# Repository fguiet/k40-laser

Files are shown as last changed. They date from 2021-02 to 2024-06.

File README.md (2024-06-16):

# K40 Laser

## Foreword

This is all about my K40 Laser improvements ...

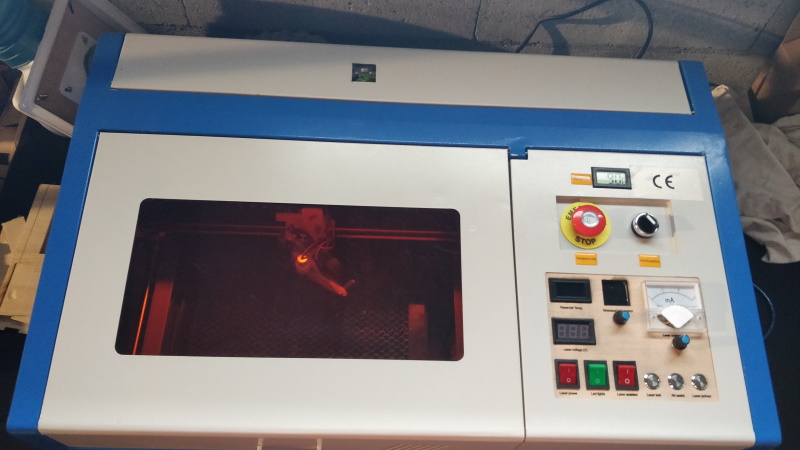
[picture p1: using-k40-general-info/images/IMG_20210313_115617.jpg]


Thanks goes to (Great French resources) :

* Jean-Philippe Civade : <https://www.civade.com>
* Barbatronic : 

Youtube : <https://www.youtube.com/barbatroniclive>

Twitch : <https://www.twitch.tv/barbatroniclive>

Twitter : <https://twitter.com/barbatronic>

## General information / Caution / Rule of thumb / Recommandations

Details avalaible [here](using-k40-general-info/using-k40-laser-cutter.md)

## K40 - Legs/foot improvement

Details avalaible [here](custom-foot/foot-improvements.md)

__Documentation status :__

2021/03/13 : Up to date and finished

## K40 - Custom motorized bed

Details avalaible [here](motorized-bed/motorized-bed-upgrade.md)

__Documentation status :__

2021/03/13 : Add paragraph on how using bed level software with pictures

... WORK IN PROGRESS ... DOCUMENTATION BEING WRITTEN ... WORK IN PROGRESS ... 

TODO : add electronic datasheet

## K40 Upgrade control panel

Details avalaible [here](control-panel/control-panel-upgrade.md)

__Documentation status :__

2021/03/13 : Add photo of my upgraded control panel

... WORK IN PROGRESS ... DOCUMENTATION BEING WRITTEN ... WORK IN PROGRESS ... 

TODO : write all the documentation of the modifications I did + add electronic datasheet

## K40 - Air Assist

Details avalaible [here](air-assist/air-assist.md)

## K40 - Lens & Mirrors alignments and upgrade

TODO

## K40 - Setting proper laser focus

Details avalaible [here](laser-focus/setting-laser-focus.md)

## K40 - Flowmeter holder

Details avalaible [here](flowmeter/flowmeter-upgrade.md)

## Bibliography / References

* [Great French references about K40 Laser Cutter - Github Barbatronic](https://github.com/nadarbreicq/Barbatronic/tree/master/laser%20k40)

Barbatronic's GitHub is full of DIY resources (robotic, PCD, FreeCAD, etc)

* [In French - General information - Blog de Iooner](https://iooner.io/k40-laser/)

* [Amélioration de la K40 - pointeur laser et Air Assist](https://www.youtube.com/watch?v=AwNY7BHcYXY)

* [K40 Tutorials / Ressources](https://k40.se/)

* [In French - Xmas ball](https://www.youtube.com/watch?v=sS2zOudljEQ)

* [In French - Améliorations / Hacking](https://www.civade.com/post/2020/08/23/D%C3%A9coupe-laser-CO2-K40-Am%C3%A9liorations-/-hacking-de-la-machine)

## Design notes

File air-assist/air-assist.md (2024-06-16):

# K40 Air Assist upgrade

A French guy called `Barbatronic` has made a very cool air assist design. Here is a link to the video (in French) where he explained how it did it : <https://www.youtube.com/watch?v=AwNY7BHcYXY>

STL files can be downloaded here : <https://github.com/nadarbreicq/Barbatronic/tree/master/laser%20k40/air%20assist/stl>

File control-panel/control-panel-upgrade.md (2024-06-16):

# K40 - Control panel upgrade

__!!! WORK IN PROGRESS ... DOCUMENTATION BEING WRITTEN ... WORK IN PROGRESS ... !!!__

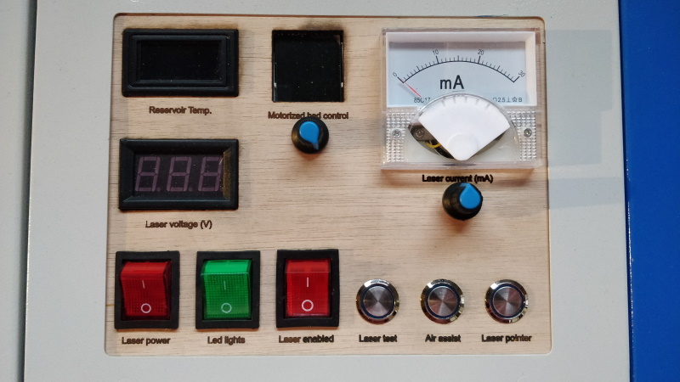
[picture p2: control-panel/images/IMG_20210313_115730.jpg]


Upgrade analog power setting
https://k40.se/k40-laser-upgrades/analog-power-setting/

## Bill of Materials

| Designation | Quantity | Price (euros) |
|:---:|:---:|:---:|
| [Blue Circle + fixed self-locking + China + 9-30V(12V) + 16mm](https://fr.aliexpress.com/item/4001291695467.html?spm=a2g0s.9042311.0.0.1fc66c37ERyqmR) | 2 | 1.69 |
| [Blue Circle + Momentary self-reset + China + 9-30V(12V) + 16mm](https://www.aliexpress.com/item/12-16-19-22mm-Waterproof-Metal-Push-Button-Switch-LED-Light-Momentary-Latching-Car-Engine-Power/4001291695467.html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) | 1 | 1.50 |

TODO : To be continued ...

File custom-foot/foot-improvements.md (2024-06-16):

# K40 Laser - foot improvements

My K40 came with "roller foot /leg" (dunno the exact english translation). What on earth did they install roller foot on that device...in my opinion this is quite useless !

A french guy called `Barbatronic` designed simple cool standstill legs that can be 3D printed.

Here is the STL file link : <https://github.com/nadarbreicq/Barbatronic/tree/master/laser%20k40/pieds%20laser>

Even better he did a very nice video about this improvement (this guy is amazing!) : <https://www.youtube.com/watch?v=EUyNfkmQzwM&feature=youtu.be>

In the beginning, I wanted to design my own legs but eventually I used nice `Barbatronic` design !

Here is the result :

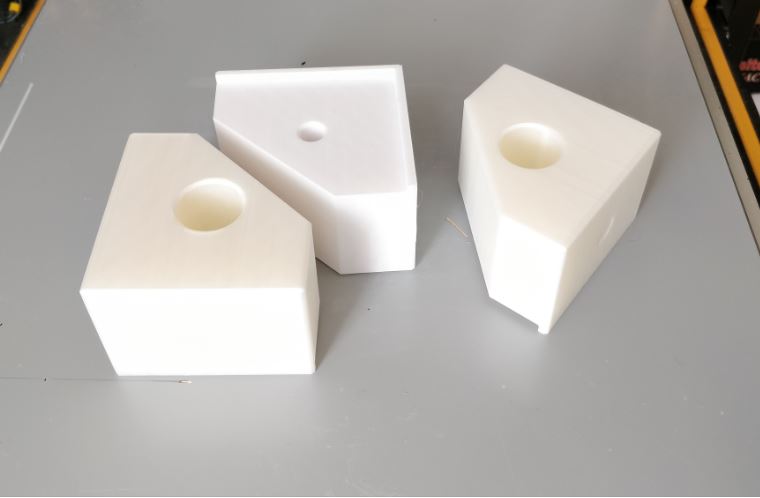
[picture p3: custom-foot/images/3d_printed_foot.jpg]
3D Printed foot


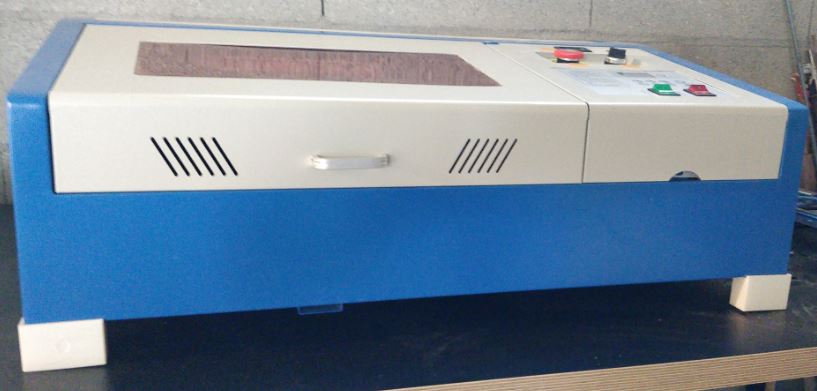
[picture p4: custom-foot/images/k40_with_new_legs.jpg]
3D Printed foot


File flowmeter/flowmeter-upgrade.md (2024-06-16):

# Flowmeter holder

This is a flowmeter holder I realised with FreeCAD 0.20

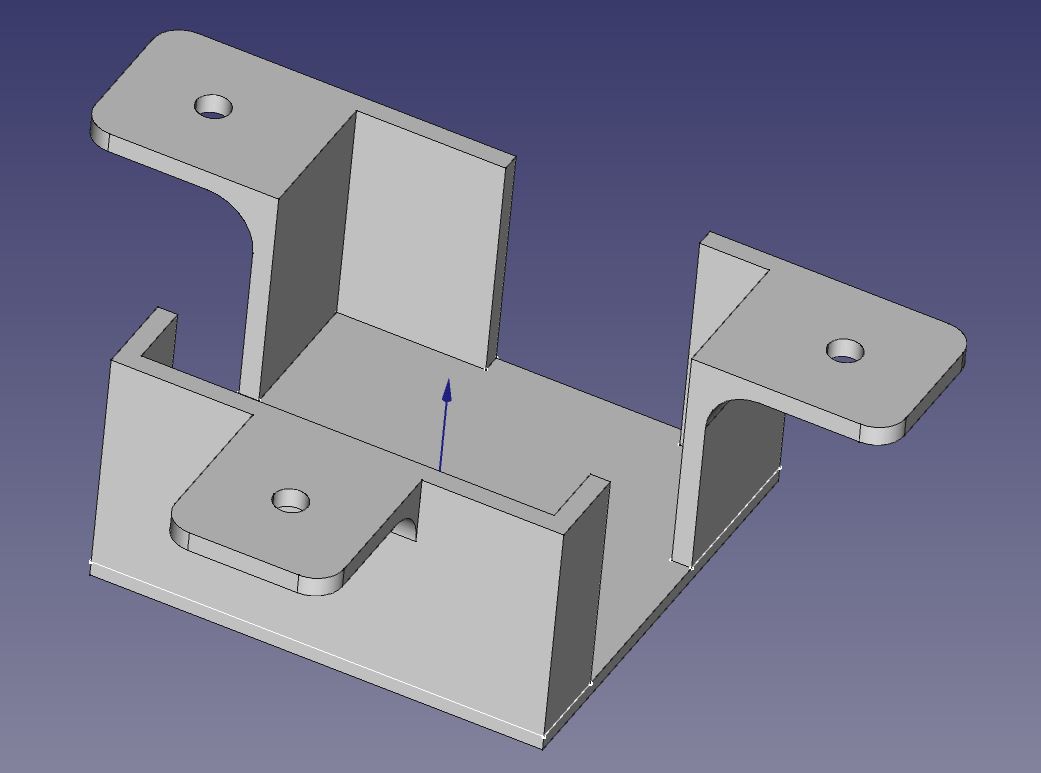
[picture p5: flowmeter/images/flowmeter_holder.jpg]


It may be used to hold this kind of flowmeter, one can found on [Aliexpress](https://fr.aliexpress.com/item/32822267913.html?spm=a2g0o.9042311.0.0.1ec66c37fij9EE).

Dimension 40x40x25 mm

But mine is 40,4mm x 40,4mm x 21,6 mm

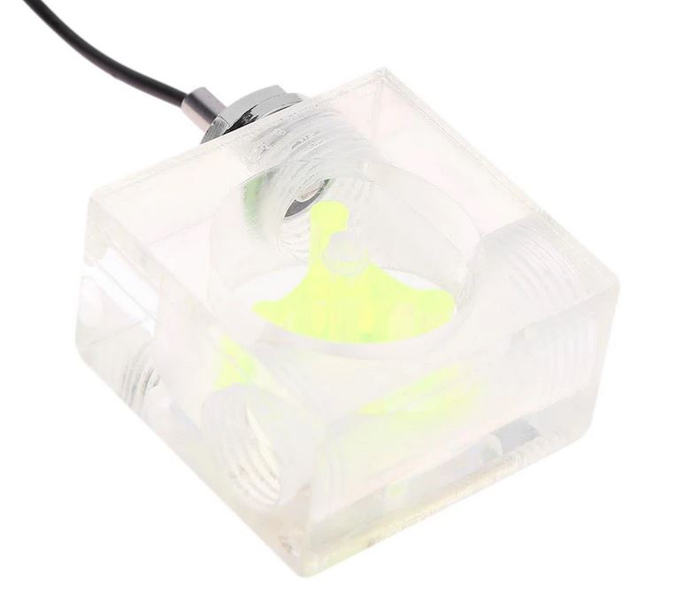
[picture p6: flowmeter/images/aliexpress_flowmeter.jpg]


Feel free to download the

* [STL File](stl/flowmeter_holder.stl)
* [FreeCAD File](FreeCAD/flowmeter_holder.FCStd)

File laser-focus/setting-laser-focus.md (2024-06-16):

# Setting laser focus

K40 laser cutter comes with a focal length of 50.8 mm. So in theory, your bed level should be good if your bed is 50.8 mm away from the laser lens.

There is a good video you can watch here : <https://www.youtube.com/watch?v=u4YHbDBBofg&t=301s>

* Make your bed level. To do that mesure the distance from the nut to top part of the bolt.
The distance must be the same on the four bed corners.

* Select "Move to bed origin" on the control panel menu. Your bed will go down to the origin.

* Use a piece of plywood and a block in order to make a ramp.

* Use `Inkscape` to draw a 20 cm line. Set the outline in blue (Recognized as Laser engrave in `Whisperer`)

* Use `Whisperer` to laser engrave the plywood (20 mm/s at 5mA, those settings can be ajusted)

* Find the spot where the line is the narrowest

* Use a rule to measure the distance between where the line is the narrowest and the laser head

* On the control panel menu, select `Move from origin to bed focal` and use `Bed offset from origin to focal` to adjust the distance from the bed to the laser head with the distance measured just before

* Save your settings : from main menu `Settings`, and `Save settings`

* You're done !

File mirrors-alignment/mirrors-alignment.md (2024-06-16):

# K40 - Lens & Mirrors alignments and upgrade

TODO

https://www.youtube.com/watch?v=e1c3keOKL6Y

## Bill of Materials

| Name | Price  |
|:---:|:---:|
| [SI 20x3mm 3Pcs + 50.8mm + Focus Lens 12mm 1Pcs](https://fr.aliexpress.com/item/32989511290.html?spm=a2g0s.9042311.0.0.1fc66c37ERyqmR) | 20.19 Euros |

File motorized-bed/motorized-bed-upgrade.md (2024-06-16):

# K40 - Motorized bed upgrade

__!!! WORK IN PROGRESS ... DOCUMENTATION BEING WRITTEN ... WORK IN PROGRESS ... !!!__

Quick and dirty videos, I have made : 

* <https://youtu.be/IQfGlTcqH2U>

* <https://youtu.be/5MnR36rrxaM>

## Foreword

K40 Laser cutter comes with an awful useless bed so I decided to make my own motorized bed.

There are some resources on the Internet about how to realize a motorized bed for your K40 Laser cutter.

In particular, I was inspired by:

__mumpitz_82__ Youtube video : <https://www.youtube.com/watch?v=evmyce_BSfk>

__Tako Schotanus__ Youtube video : <https://www.youtube.com/watch?v=CWHxK8Uck-s>

But the best resources is from Jean-Philippe Civade : <https://www.civade.com> (it's in French though) :

<https://www.civade.com/post/2020/08/23/D%C3%A9coupe-laser-CO2-K40-:-R%C3%A9alisation-d-un-lit-motoris%C3%A9>

Everything is explained in details. Thanks for sharing !

## Making the motorized bed frame

Top view

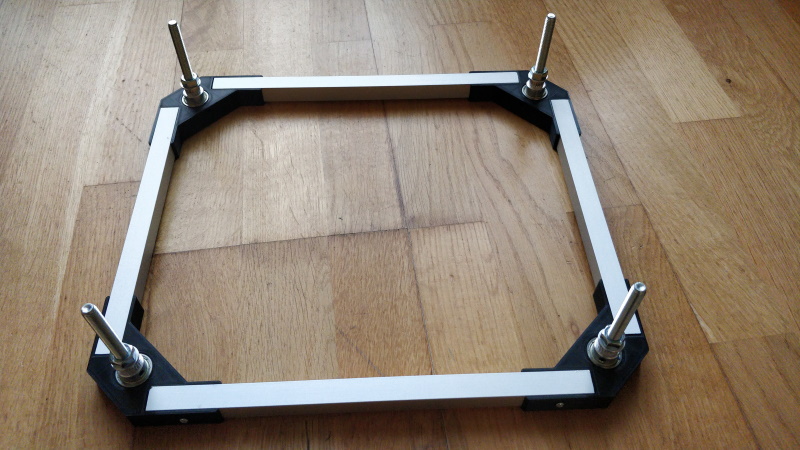
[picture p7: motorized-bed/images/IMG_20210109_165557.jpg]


Bottom view

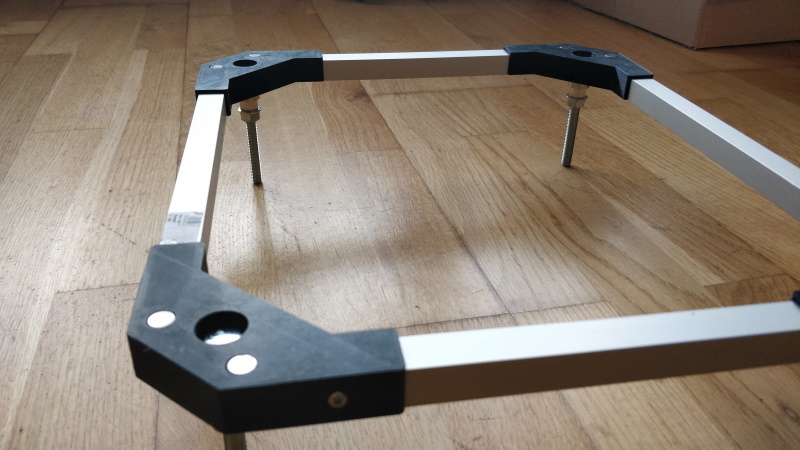
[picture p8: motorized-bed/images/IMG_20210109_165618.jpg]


With belt (final version does not have the belt tensioner. I am using 1250 mm that fits my design now)

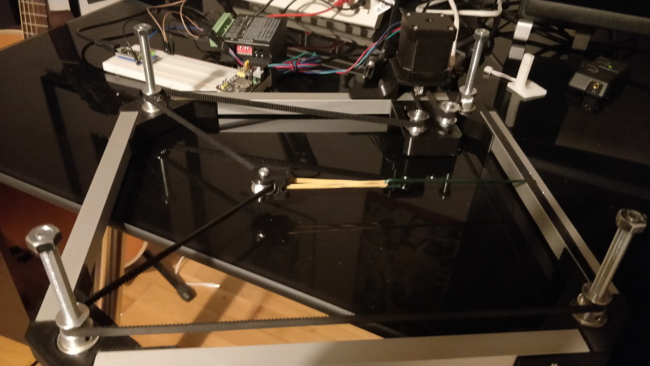
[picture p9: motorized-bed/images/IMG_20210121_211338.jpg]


With belt and bed (final version does not have the belt tensioner. I am using 1250 mm that fits my design now)

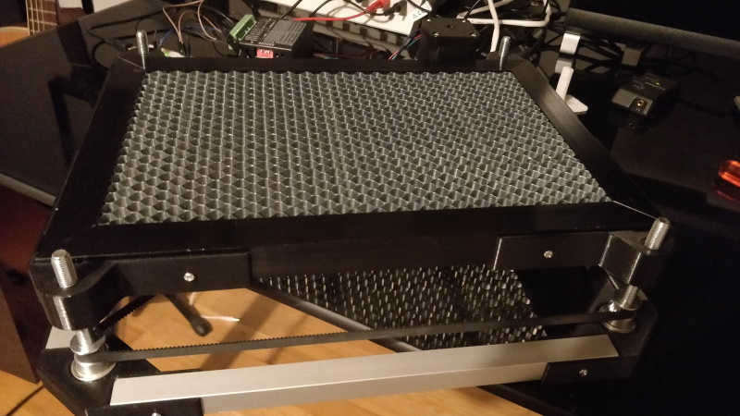
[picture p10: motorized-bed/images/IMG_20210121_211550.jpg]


All 3D print parts needed are available here : <https://www.thingiverse.com/thing:4778552>

* 3D Print 4 corners : STL file `motorized-bed-base-corner-frame.stl`
* Cut 4 pieces of 15 x 15 mm aluminium tube (2 pieces of 26.1 cm lenght and 2 pieces of 22.2 cm lenght)
* Assemble the 3D print parts and the aluminium tubes
* Use a 2.5 mm drill bit to drill hole in the aluminium part
* Use a tap and die (Tarauds in French) M3 x 0.5mm 
* Use 8 x M3 bolt to tight the 3D Print part with the alumnium part
* Add the four 608ZZ bearings on the 3D Print parts
* Add the four M8 x 8mm bolts and nuts
* Add the four GT2 8mm (diameter) x 6 mm height pulleys 
* You're done !
* BONUS : Add 8 neodymes magnet (8mm x 1mm) of the bottom corner

## Bed level software

Software used to develop : Visual Studio Code + PlatformIO plugin.

Self-explanatory open source code, see folder : `sketches\k40-motorized-bed` on this GitHub.

* Using the bed level software

__Powering the K40 laser ON__

1. make the splash screen quickly appear
2. bed will retrieve its origin
3. bed will move up to the material focal point (engrave) level, that is to say : 

bed level to best laser focal length lens (should be around 50.8 mm) minus material thickness

Example in my case:

14 mm - 5 mm = 9 mm 

14 mm : distance of the bed from the bed origin so the laser focal distance from the bed is around 50.8 mm (default K40 focal length lens). See [Settings laser focus](../laser-focus/setting-laser-focus.md), to understand how I find my setting of 14 mm

5 mm : current material thickness (can be changed)

Splash screen

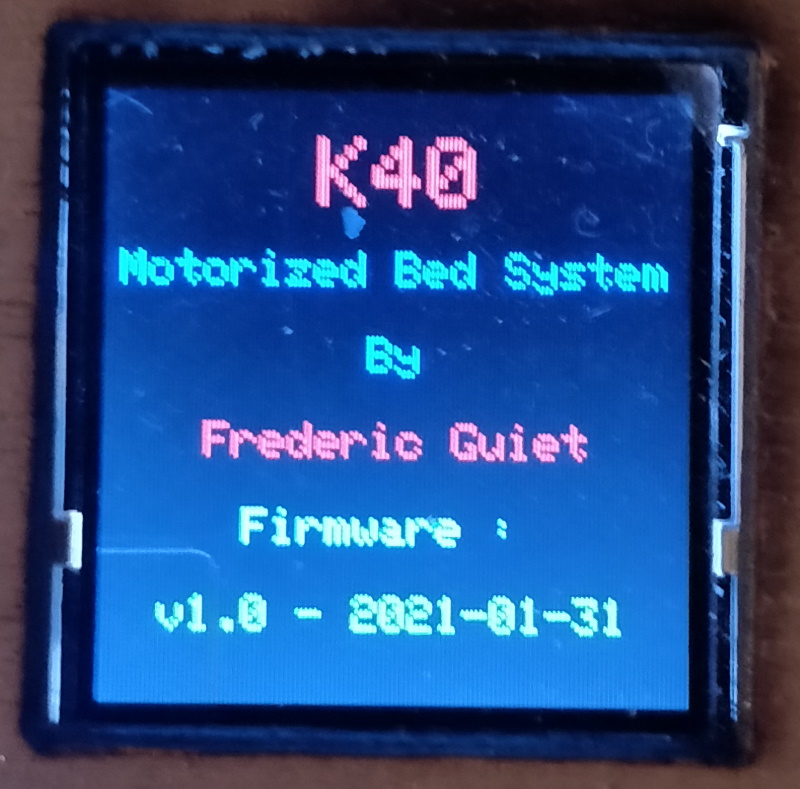
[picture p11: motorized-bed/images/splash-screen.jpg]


Bed retrieving its origin

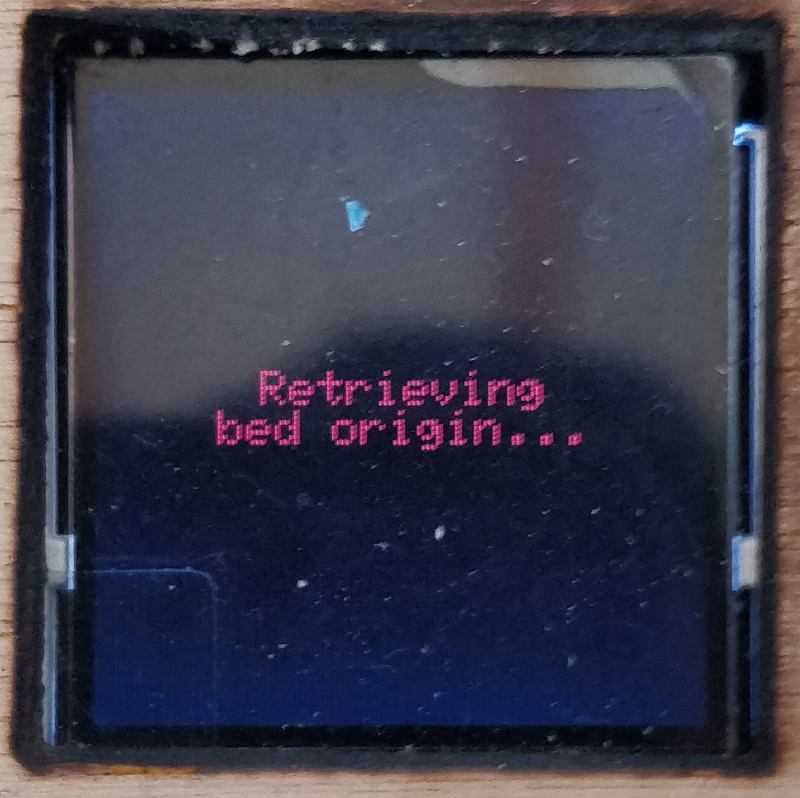
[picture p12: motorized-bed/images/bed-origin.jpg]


__Main menu__

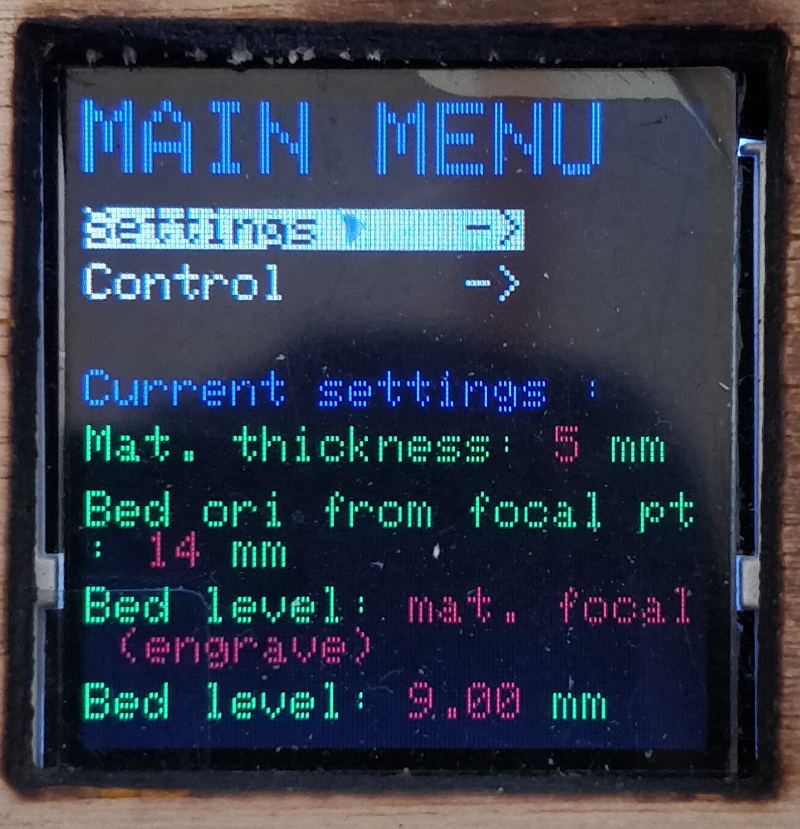
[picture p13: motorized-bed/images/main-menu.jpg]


Main menu is made up of (to enter any menu, just hold the button for about half a second) :

1. Settings menu

When entering this menu, you will be able to set/change default material thickness, bed offset from origin to best focal lenght lens (See [Settings laser focus](../laser-focus/setting-laser-focus.md))

2. Control menu 

When entering this menu, you will be able to move the bed to different level (origin, engrave, cut)

3. Current settings values

This is a sum up of the current settings. 

Current material thickness

Current bed origin to best focal point distance. See [Settings laser focus](../laser-focus/setting-laser-focus.md)

Bed level status : engrave (= laser focal point minus material thickness), cut (= laser focal point minus material thickness / 2), origin, laser focal point (distance between bed and laser lenght should be around 50.8 mm)

Current bed level from origin (depends on bed status)

__Settings menu__

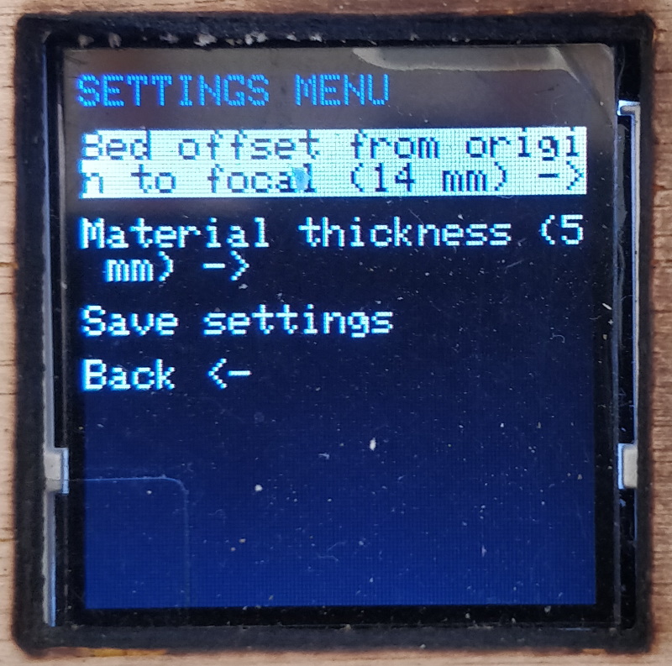
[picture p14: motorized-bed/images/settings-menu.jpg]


Here you can change defaults parameters and save them.

You can change :

The default distance between bed origin and the bed so the bed distance between bed and best focal length lens is around 50.8 mm (again see [Settings laser focus](../laser-focus/setting-laser-focus.md)). Use the menu `Bed offset from origin to focal (xx mm) ->`

The default material thickness. This setting is used to compute automatically the bed level used for engraving or for cutting. Use the menu `Material thickness (x mm) ->`

The following formulas are applied :

Bed level (cut) = bed level offset from origin to best focal point minus material thickness divided by 2
Bed level (engrave) = bed level offset from origin to best focal point minus material thickness

To change the value : hold the button for half a second then you will be able to change the value by turning the button clockwise or anti-clockwise

You can persist your settings by entering the `Save settings` menu

__Control menu__

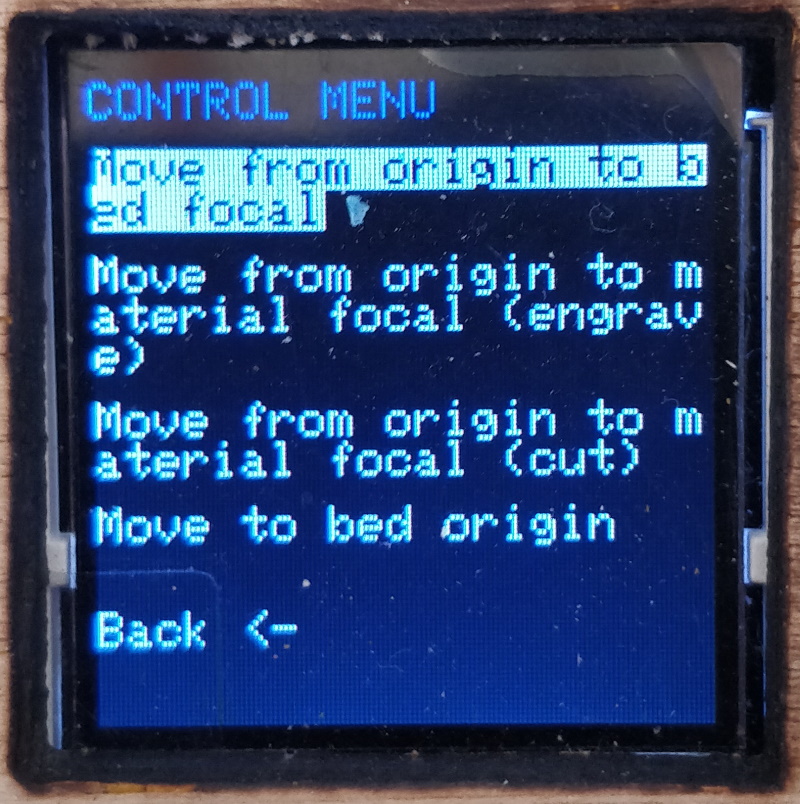
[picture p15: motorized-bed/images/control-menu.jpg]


With the control menu, you will be able freely change your bed level.

`Move from origin to focal (xx mm)` : make your bed go from bed origin to focal point ... quite obvious...the distance can be set using `Settings menu`

`Move from origin to material focal (engrave)` : make your bed go from bed origin to focal point minus material thickness

`Move from origin to material focal (cut)` : make your bed go from bed origin to focal point minus material thickness divided by 2

`Move to bed origin` : make your bed go to the bed origin (lowest point the bed can go). Maybe useful if you want to pull your bed out of your K40.

## Electronic datasheet

TODO : __!!! WORK IN PROGRESS ... DOCUMENTATION BEING WRITTEN ... WORK IN PROGRESS ... !!!__

## BOM (Bill of materials)

| Designation | Quantity | Price (euros) |
|---|---|---|
| [Neodyme magnet 8mm x 1mm](https://fr.aliexpress.com/item/1005001485065704.html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,searchweb201602_,searchweb201603_) | 10 | 1.6 |
| [Roulement 608ZZ](https://www.amazon.fr/gp/product/B07RZ651J7/ref=ppx_yo_dt_b_search_asin_title?ie=UTF8&psc=1) | 1 | 10 |
| [Module LCD TFT couleur SPI 1.44 pouces série 128x128](https://fr.aliexpress.com/item/32805710090.html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,searchweb201602_,searchweb201603_) | 1 | 2.36 |
| [Power supply : 12v, 3A](https://fr.aliexpress.com/item/32983648084.html?spm=a2g0s.9042311.0.0.27426c379UWNDo) | 1 | 5.47 |
| [Module d'encodeur rotatif 360 degrés](https://fr.aliexpress.com/item/32648520888.html?spm=a2g0s.9042311.0.0.1ec66c37pUfP6L) | 1 | 0.67 |
| [Arduino Uno](https://fr.aliexpress.com/item/32272099710.html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,searchweb201602_,searchweb201603_) | 1 | 2.86 |
| M3 Bolt | 8 | ? |
| Bolt M8 x 80mm | 4 | ? |
| Nut M8 | 4 | ? |
| [End stop switch](https://fr.aliexpress.com/item/32824972155.html?spm=a2g0s.9042311.0.0.27426c37mAJldV) | 1 | 0.59 |
| [GT2 Belt 1250 mm](https://fr.aliexpress.com/item/4000307078477.html?spm=a2g0s.9042311.0.0.70226c377k5Fyv) | 1 | 1.76 |
| [Entretoise](https://www.amazon.fr/gp/product/B07RP6CRD5/ref=ppx_yo_dt_b_asin_title_o01_s00?ie=UTF8&psc=1) | 1 | 15 |
| [Stepper Driver Motor TB6600](https://www.amazon.fr/gp/product/B0811GSPJK/ref=ppx_yo_dt_b_asin_title_o04_s00?ie=UTF8&psc=1) | 1 | 13.49 |
| [Tube carré - aluminium, couleur argent, anodisée, 1000 x 15 x 15 mm](https://www.amazon.fr/gp/product/B0029ZTDKM/ref=ppx_od_dt_b_asin_title_s00?ie=UTF8&psc=1) | 3 | 8.36 |
| [DollaTek 5PCS Aluminium GT2 Courroie De Distribution Poulie 20 Dents Alésage 8mm Largeur 6mm et Clé pour RepRap 3D Imprimante Prusa i3](https://www.amazon.fr/gp/product/B07DK1J8ZD/ref=ppx_yo_dt_b_asin_title_o09_s01?ie=UTF8&psc=1) | 1 | 8 |
| [Quimat 3x Nema 17 Stepper Moteur,Moteurs pour Imprimante 3D 1.7A 0.59Nm](https://www.amazon.fr/gp/product/B06XQWMDWT/ref=ppx_yo_dt_b_asin_title_o09_s02?ie=UTF8&psc=1) | 1 | 40 |
| [Table de travail en nid d'abeille pour graveur Laser CO2, pièces pour Machine de découpe Shenhui SH K40 graveur de timbres 320x220mm](https://fr.aliexpress.com/item/32603523206.html?spm=a2g0s.9042311.0.0.27426c37F8tu4Z) | 1 | 13.96 |

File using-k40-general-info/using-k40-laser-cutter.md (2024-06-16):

# Using K40 Laser Cutter – The rules of thumb

## Default Settings

* Laser cut area (my upgraded version) : 280mm x 180 mm

* Laser tube power : 40 W

* Lens diameter : 12 mm

* Focal lenght : 50.8 mm

* 3 Mirrors : 20 mm

I bought mine on AliExpress : <https://fr.aliexpress.com/item/1005001374933857.html?spm=a2g0s.9042311.0.0.27426c37F8tu4Z>

I have choosen a warehouse located in Czech Republic and I have paid : __349 euros (with DHL shipping included)__

## Powering the CO2 Tube

* [Do not overpower the CO2 Tube](https://k40.se/k40-laser-troubleshooting/dead-lasertube/). Keep the ammeter below 18mA (which is around 2.5v on the voltmeter of my K40).

Below the value in mA I get when I set some value on the voltmeter (Caution, this is my settings, it may differ on yours) 

| Value set on the Voltmeter (in V) | Match value on the ammeter (in mA) |
|---|---|
| 0.5 | 3 |
| 1 | 7 |
| 1.25 | 9 |
| 1.4 | 10 |
| 1.5 | 10-11 |
| 1.6 | 11 |
| 1.8 | 12 |
| 2 | 13 |
| 2.1 | 14 |
| 2.3 | 15 |
| 2.5 | 16 |
| 2.7 | 17 |
| 2.9 | 18 |

## Cooling water

* Only use pure distilled water, never add watercooling stuff

## Before turning the machine ON

* __Put your CO2 Laser proof google on__
* Check all buttons are in OFF position
* Check that your potentiometer is set to the minimum (ie you should not be able to turn it anticlockwise)
* [Check CO2 Laser tube water temperature](https://k40.se/k40-laser-troubleshooting/dead-lasertube/), it should be between 15-20 °C. It can run if temperature is between 21-23°C but it reduces the CO2 tube life time.
* From time to time, check bed leveling

## Turning the machine ON

1.	Turn the water pump ON and eliminate all the bubbles in the CO2 Laser tube (on my laser I need to raise it towards me to get rid of bubbles on the left side of the laser tube)
2. 

TODO : Finish this part

## What can be cut ?

French ressource : <https://iooner.io/decoupe-laser-les-materiaux/>

Some working parameters I have tested:

* Plywood (don't think it is made of poplar...)

Cut : 5 mm/s, 16 mA (2.5v)...but there are places not cut very well...dunno why (laser alignment? bed leveling?)

## BOM (Bill Of Materials)

| Name | Price  |
|:---:|:---:|
| [CO2 Laser protection google  9000-11000 nm](https://www.amazon.fr/gp/product/B07JCSH4HC/ref=ppx_yo_dt_b_asin_title_o02_s00?ie=UTF8&psc=1) | 40 Euros |

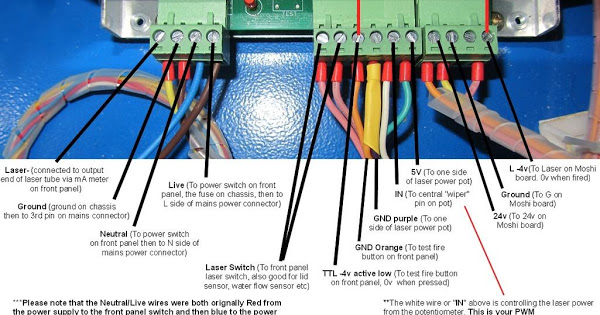
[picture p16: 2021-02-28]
control-panel/images/power_pinout.jpg

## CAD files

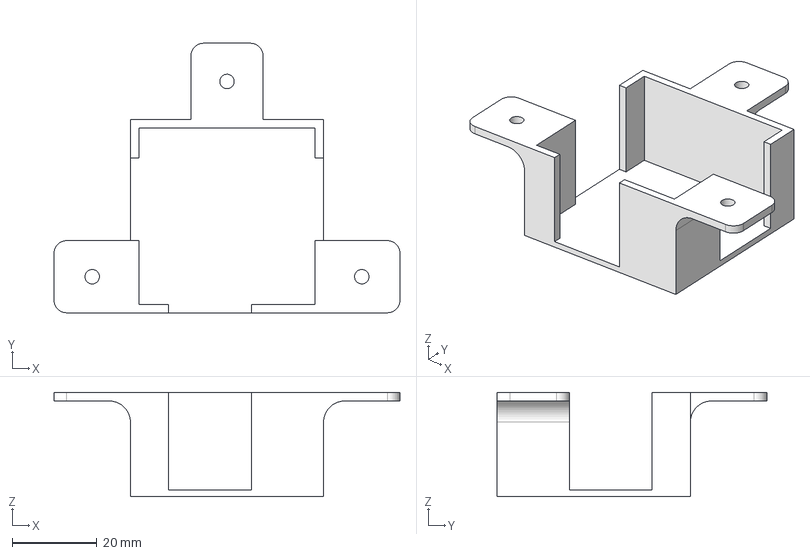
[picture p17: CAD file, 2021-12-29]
flowmeter/FreeCAD/flowmeter_holder.FCStd
81.5 x 63.5 x 24.5 mm

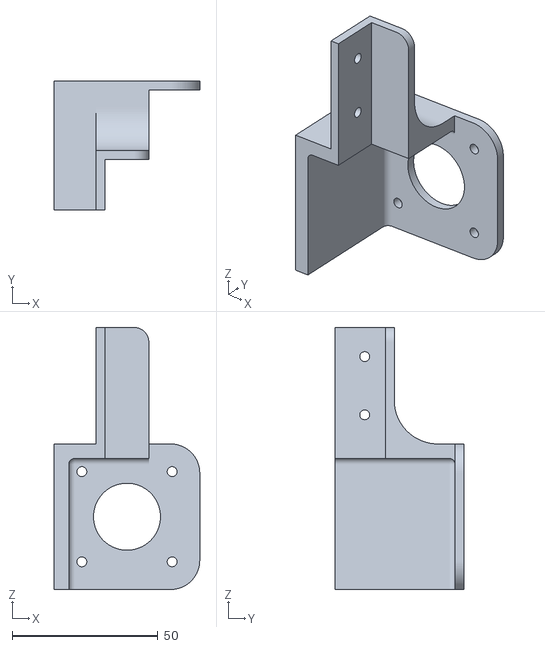
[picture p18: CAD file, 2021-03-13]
motorized-bed/stl/motorized-bed-nema17-holder.stl
50.0 x 44.2 x 90.0

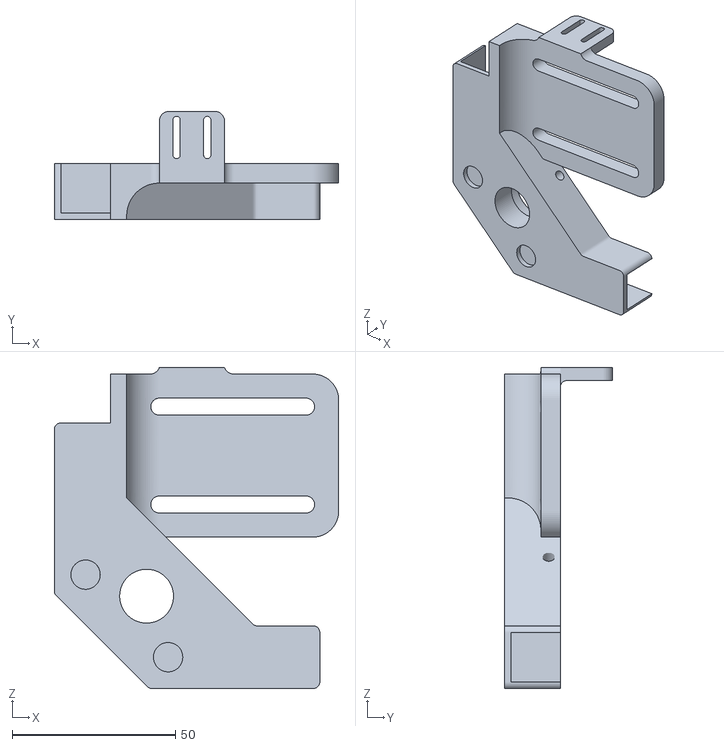
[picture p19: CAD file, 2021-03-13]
motorized-bed/stl/motorized-bed-base-upper-right-corner.stl
87.2 x 33.2 x 98.4

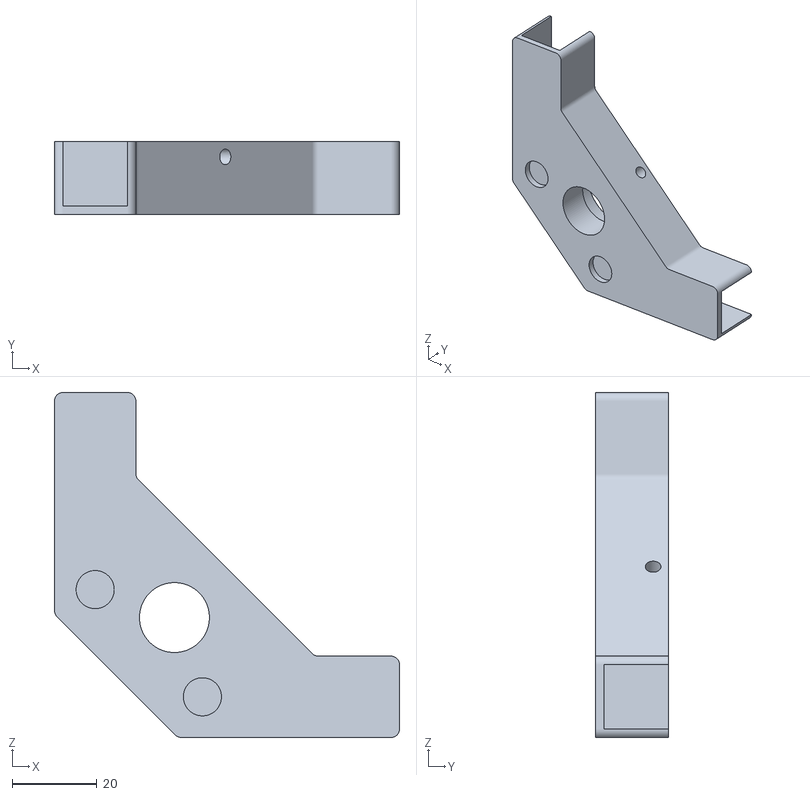
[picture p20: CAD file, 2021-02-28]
motorized-bed/stl/motorized-bed-base-corner-frame.stl
81.4 x 17.2 x 81.4

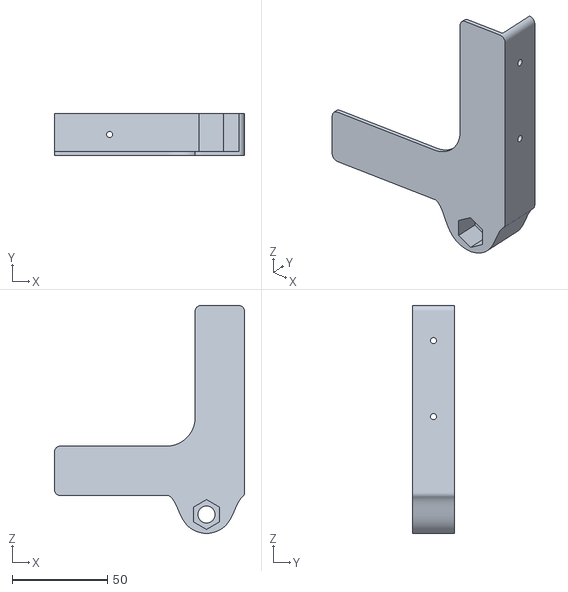
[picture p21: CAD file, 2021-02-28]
motorized-bed/stl/motorized-bed-upper-right-corner.stl
100.0 x 22.0 x 120.0

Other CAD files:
motorized-bed/stl/motorized-bed-bottom-left-corner.stl
motorized-bed/stl/motorized-bed-upper-left-corner.stl
motorized-bed/stl/motorized-bed-bottom-right-corner.stl
flowmeter/stl/flowmeter_holder.stl

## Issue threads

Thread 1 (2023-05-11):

k40-motorized-bed

interceptor70, 2023-05-11:
Hi from Germany

s the project still active?

how can i adjust two lenses i need one 50 and one 90 mm
can this be expanded?

LG Interceptor

interceptor70, 2023-06-03:
need 0.1 mm thigness auch

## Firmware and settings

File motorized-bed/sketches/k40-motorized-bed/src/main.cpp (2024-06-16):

/*
* K40 laser cutter - Motorized bed
* Frédéric Guiet - 01/2021
* 
* I wrote this piece of software but it is inspired from the one wrote by Jean-Philippe Civade : https://www.civade.com/post/2020/08/23/D%C3%A9coupe-laser-CO2-K40-%3A-R%C3%A9alisation-d-un-lit-motoris%C3%A9
*
*/

// ****** External librairies used ******

#include <SPI.h>            // needed by TFT_ILI9163C
#include <Adafruit_GFX.h>   // Adafruit graphic library needed by TFT_ILI9163C
#include <Wire.h>           // needed by TFT_ILI9163C
#include <ezButton.h>       // Button management
#include <Encoder.h>        // Panel encoder management from Paul Stoffregen
#include <AccelStepper.h>   // To manager stepper with acceleration
#include <TFT_ILI9163C.h>   //TFT ILI9163C 128x128 Screen management

// ****** DEBUG *************************

#define DEBUG 1

// ***** FIRMWARE ***********************

#define FIRMWARE "v1.0 - 2021-01-31"

// **************************************

// ****** NEMA17 MOTOR SETTINGS *********

//* Motor NEMA 17 (https://www.amazon.fr/gp/product/B06XQWMDWT/ref=ppx_yo_dt_b_asin_title_o06_s01?ie=UTF8&psc=1)
//*
//* NEMA 17, Peak current 1.7A, 200 steps per revolution, 1.8° per step
//*
//* Driver TB6600 (https://www.amazon.fr/gp/product/B0811GSPJK/ref=ppx_yo_dt_b_asin_title_o01_s00?ie=UTF8&psc=1)
//*
//* Microstep settings
//* Stepper motors typically have a step size of 1.8° or 200 steps per revolution, this refers to full steps. A microstepping driver such as the TB6600 allows higher resolutions by allowing intermediate step locations. This is achieved by energizing the coils with intermediate current levels.
//* For instance, driving a motor in 1/2 step mode will give the 200-steps-per-revolution motor 400 microsteps per revolution.
//* You can change the TB6600 microstep settings by switching the dip switches on the driver on or off. See the table below for details. Make sure that the driver is not connected to power when you adjust the dip switches!
//*
//* Steps (1,2,3) = 0ff, On, Off = 1/8 step
//* Power (4,5,6) = On,On, Off) = 1.5A nominal / 1.7 Peak
//*
//* Wire Blue = B+
//* Wire Red  = B-
//* Wire Green = A+
//* Wire Black = A-
//
// So...
//
// See : https://fr.wikipedia.org/wiki/Filetage_m%C3%A9trique
//
// * 200 * 8 = 1600 micro-step / turn.
// * Screw M8 x 1.25 (1.25 mm per thread)
// * 1 turn = 1.25 mm = 1600 steps
// * 1mm = (1600/1.25)*1 = 1280 steps
// * 0.1mm = 128 steps

// Pin configuration Arduino to TP6600 Driver
// Arduino Digital pin 4 to PUL-(PUL)
// Arduino Digital pin 5 to DIR-(DIR)
// Arduino Digital pin 6 to ENA-(ENA)

// Stepper connections
#define  STEP_PIN 4             // Step/Pulse interface ()
#define  DIRECTION_PIN 5        // Dir interface (Nema 17 Direction)
#define  ENABLE_PIN 6           // Enable stepper motor (Enable / disable current on Nema 17)

// Stepper constants
#define STEPS_PER_MM 1280.0      // Number of step needed for 1 mm

// Library objects instantiation
AccelStepper bed(AccelStepper::DRIVER, STEP_PIN, DIRECTION_PIN);

#define MAX_BED_OFFSET_FROM_ORIGIN 18 //max offset from switch to bed focal zero (mm)
#define MAX_MATERIAL_THICKNESS 50  //max material thickness (mm)

#define DEFAULT_BED_OFFSET_FROM_ORIGIN 18 //Default offset from switch to bed focal zero (mm)
#define DEFAULT_MATERIAL_THICKNESS 5  //Default material thickness (mm)

#define RESET_FLASH_MEMORY_PIN 8

// ********** BED STATUS ************

enum bedStatus { FROM_ORIGIN_TO_BED_FOCAL_POINT_LEVEL, FROM_ORIGIN_TO_MATERIAL_ENGRAVE_FOCAL_POINT_LEVEL, FROM_ORIGIN_TO_MATERIAL_CUT_FOCAL_POINT_LEVEL, FROM_ORIGIN_LEVEL };

// bed settings vars
typedef struct {    
    int bedOffsetFromOriginToFocalPoint_mm = DEFAULT_BED_OFFSET_FROM_ORIGIN; //Default offset from switch to bed focal zero (mm)
    int materialThickness_mm = DEFAULT_MATERIAL_THICKNESS; //Default material thickness    
    //int materialOffsetFromOriginToFocalPoint_mm = DEFAULT_BED_OFFSET_FROM_ORIGIN - DEFAULT_MATERIAL_THICKNESS;  


  //float fBedOffset;       // Default offset from switch to bed focal zero (mm)
  //float fMaterialOffset;  // Default offset from bed to surface to cut's bottom (mm)  
  //bool  bCut;             // Cut y/n (boolean)
  //float fTickness;        // Material tickness (mm). Used to compute real offset. 
                          // For engraving (bCut=0), focal point is set to material surface
                          //      Focal point = fBedOffset + fMaterialOffset + fTickness
                          // For cutting (bCut=1), focal point is is in the middle of the material
                          //      Focal point = fBedOffset + fMaterialOffset + fTickness/2 
} bedSettingsType;
bedSettingsType bedSettings;

typedef struct {    
    float materialOffsetFromOriginToEngraveFocalPoint_mm;
    float materialOffsetFromOriginToCutFocalPoint_mm;
    long materialOffsetFromOriginToBedFocalPoint_steps;
    long materialOffsetFromOriginToEngraveFocalPoint_steps;
    long materialOffsetFromOriginToCutFocalPoint_steps;
    bedStatus bed_level_status = FROM_ORIGIN_TO_MATERIAL_ENGRAVE_FOCAL_POINT_LEVEL;
    
} bedComputedSettingsType;
bedComputedSettingsType bedComputedSettings;


// ****** HOME SWITCH BUTTON SETTINGS **********

#define  HOME_SWITCH_PIN 7            // home switch (set the 0 level of the bed)

// ****** ROTARY ENCODER SETTINGS REF : HW-040 **************

// Encoder connections
// work best with interrupts enabled pin (2,3 with Arduino board)
#define ENCODER_BUTTON_PIN A0         //A0 can be used as digital pin
#define ENCODER_1_PIN 2       
#define ENCODER_2_PIN 3      
#define LONG_PRESS_TIME 500 // 500 milliseconds

// HW040 - ENCODER 
//SW = ENCODER_BUTTON_PIN
//CLK = PIN 3
//DT =  PIN 2
ezButton encoderButton(ENCODER_BUTTON_PIN);  // create ezButton object that attach to pin A0;
Encoder encoder(ENCODER_1_PIN, ENCODER_2_PIN);

// ****** DISPLAY SETTINGS **************

//
//DID YOU HAVE A RED PCB, BLACk PCB or WHAT DISPLAY TYPE???????????? 
//GOT THE BLACK ONE so I needed to edit file below otherwise screen will display glitches
//
// See https://github.com/sumotoy/TFT_ILI9163C 
//
// See TFT_ILI9163C_settings.h file
//  ---> SELECT HERE <----
//#define __144_RED_PCB__//128x128
//#define __144_BLACK_PCB__//128x128
//#define __22_RED_PCB__//240x320

//PIN Configuration

//TFT => Microcontroller

//VCC = +5v (check whether you have a voltage regulator first)
//GND = GND
//CS = D10 (See contructor)
//RESET = +5v (if you do not use RESET PIN)
//A0 = DC or RS pin = D9
//SDA = Mosi = D11 (See Arduino Datasheet)
//SCK = Clock = D13 (See Arduino Datasheet)
//LED = +5v or +3.3v

#define DISPLAY             // define to support TFT_ILI9163C display

#define BLACK   0x0000
#define BLUE    0x001F
#define RED     0xF800
#define GREEN   0x07E0
#define CYAN    0x07FF
#define MAGENTA 0xF81F
#define YELLOW  0xFFE0  
#define WHITE   0xFFFF

#define __CS 10
#define __DC 9 //A0

#ifdef DISPLAY
//Setup TFT Display
TFT_ILI9163C tft = TFT_ILI9163C(__CS, __DC);
#endif

// ********** MENU SETTINGS *********

enum availableOptions { MOVE_TO_BED_ORIGIN, MOVE_FROM_ORIGIN_TO_BED_FOCAL_OPTION, MOVE_FROM_ORIGIN_TO_MATERIAL_FOCAL_ENGRAVE_OPTION,
                        MOVE_FROM_ORIGIN_TO_MATERIAL_FOCAL_CUT_OPTION, MATERIAL_THICKNESS_SET_OPTION, 
                        THICKNESS_SETTINGS_OPTION, BACK_OPTION, BED_OFFSET_FROM_ORIGIN_TO_FOCAL_SET_OPTION, 
                        SAVE_SETTINGS_OPTION, SETTINGS_OPTION, CONTROL_OPTION, BED_OFFSET_FROM_ORIGIN_TO_FOCAL_OPTION };
availableOptions currentOptionSelected;

// ********** VARIABLES *************

unsigned long pressedTime  = 0; // to save when button is pressed
bool isPressing = false;        // button pressed? or not?
bool buttonPressedHandled = false; //button pressed handled ?

long absoluteBedPosition = 0;    // absolute bed position in step
long currentMaterialThickness = 0;
long currentFromOriginToBedFocalPoint = 0;

long newTicks = 0;              // handle encoder value

enum screenToDisplay { CONTROL_SCREEN, MATERIAL_THICKNESS_SCREEN, SAVING_SETTINGS_SCREEN, SPLASH_SCREEN, ORIGIN_SCREEN, 
                       DEFAULT_OFFSET_SCREEN, MAIN_MENU_SCREEN, SETTINGS_SCREEN, BED_OFFSET_FROM_ORIGIN_TO_FOCAL_SCREEN };
screenToDisplay currentScreen;
screenToDisplay oldScreen;

/*
* Debug function
*/
void debug_message(String message, bool doReturnLine) {
  if (DEBUG) {
    if (doReturnLine)
      Serial.println(message);
    else
      Serial.print(message);
    
    Serial.flush();
    delay(10);
  }
}

void writeSettings()
// be aware of eeprom longevity : only 10000 write cycles..
{
    //debug_message(F("Writing settings in flash memory..."), true);
    eeprom_write_block((const void*)&bedSettings, (void*)0, sizeof(bedSettingsType));
}

//Only writes settings if something has changed...avoid write cyvles...
void updateSettings()
// be aware of eeprom longevity : only 10000 write cycles..
{
    //debug_message(F("Updating settings in flash memory..."), true);
    eeprom_update_block((const void*)&bedSettings, (void*)0, sizeof(bedSettingsType));
}

void readSettings()
{
    int val = digitalRead(RESET_FLASH_MEMORY_PIN);
    if (val == LOW) {
        //debug_message(F("Resetting settings in flash memory..."), true);
        writeSettings();
    }
    
    //debug_message(F("Reading settings in flash memory..."), true);
    eeprom_read_block((void*)&bedSettings, (void*)0, sizeof(bedSettingsType));
}

/*
* Gets X coordinate depending on message to display so it is centered on screen
*/
int getCenterX(int msgLength, int charWidthPixelSize) {
    return (tft.width() / 2) - ((msgLength * charWidthPixelSize) / 2);
}

/*
*  Gets Y coordinate depending on message to display so it is centered on screen
*/
int getCenterY(int totalLineToDisplay, int lineNumber, int charHeightPixelSize) {
    return (tft.height() / 2 - ((charHeightPixelSize * totalLineToDisplay) / 2)) + ((lineNumber - 1) *  charHeightPixelSize);
}

/*
* Display splash screen
*/
void displaySplashScreen() {

    int totalLineToDisplay = 5;     

    String msg = "K40";
    tft.setTextSize(2);  
    int x = getCenterX(msg.length(), 12);
    int y = 10;
    tft.setCursor(x, y);
    tft.setTextColor(RED);            
    tft.print(msg);

    //Text Size 1 - 6x8
    //Text Size 2 - 12x16
    tft.setTextSize(1);         
    int charWidthPixelSize = 6;
    int charHeightPixelSize = 8;

    //#1 line
    msg = "Motorized Bed System";
    int lineNumber = 1;
    x = getCenterX(msg.length(), charWidthPixelSize);
    y = getCenterY(totalLineToDisplay, lineNumber, charHeightPixelSize);
    tft.setCursor(x, y -10 );
    tft.setTextColor(BLUE);            
    tft.print(msg);

    //#2 line
    msg = "By";
    lineNumber = 2;
    x = getCenterX(msg.length(), charWidthPixelSize);
    y = getCenterY(totalLineToDisplay, lineNumber, charHeightPixelSize);
    tft.setCursor(x, y);
    tft.setTextColor(BLUE);            
    tft.print(msg);

    //#3 line
    msg = "Frederic Guiet";
    lineNumber = 3;
    x = getCenterX(msg.length(), charWidthPixelSize);
    y = getCenterY(totalLineToDisplay, lineNumber, charHeightPixelSize);
    tft.setCursor(x, y + 10);
    tft.setTextColor(RED);            
    tft.print(msg);

    //#4 line
    msg = "Firmware : ";
    lineNumber = 4;
    x = getCenterX(msg.length(), charWidthPixelSize);
    y = getCenterY(totalLineToDisplay, lineNumber, charHeightPixelSize);
    tft.setCursor(x, y + 20);
    tft.setTextColor(CYAN);            
    tft.print(msg);

    //#5 line
    msg = FIRMWARE;
    lineNumber = 5;
    x = getCenterX(msg.length(), charWidthPixelSize);
    y = getCenterY(totalLineToDisplay, lineNumber, charHeightPixelSize);
    tft.setCursor(x, y + 30);
    tft.setTextColor(GREEN);            
    tft.print(msg);

    /*debug_message("Screen Height : " + String(tft.height()), true);
    debug_message("Screen Width : " + String(tft.width()), true);
    debug_message("X : " + String(x), true);
    debug_message("Y : " + String(y), true);*/
}

void displayDefaultOffsetScreen() {

    int totalLineToDisplay = 2;     

    //Text Size 1 - 6x8
    //Text Size 2 - 12x16
    tft.setTextSize(1);         
    int charWidthPixelSize = 6;
    int charHeightPixelSize = 8;

    //#1 line
    String msg = "Going to";
    int lineNumber = 1;
    int x = getCenterX(msg.length(), charWidthPixelSize);
    int y = getCenterY(totalLineToDisplay, lineNumber, charHeightPixelSize);
    tft.setCursor(x, y);
    tft.setTextColor(RED);            
    tft.print(msg);

    //#2 line
    msg = "default offset...";
    lineNumber = 2;
    x = getCenterX(msg.length(), charWidthPixelSize);
    y = getCenterY(totalLineToDisplay, lineNumber, charHeightPixelSize);
    tft.setCursor(x, y);
    tft.setTextColor(RED);            
    tft.print(msg);
}

void displaySavingSettingsScreen() {

    int totalLineToDisplay = 2;     

    //Text Size 1 - 6x8
    //Text Size 2 - 12x16
    tft.setTextSize(1);         
    int charWidthPixelSize = 6;
    int charHeightPixelSize = 8;

    //#1 line
    String msg = "Saving";
    int lineNumber = 1;
    int x = getCenterX(msg.length(), charWidthPixelSize);
    int y = getCenterY(totalLineToDisplay, lineNumber, charHeightPixelSize);
    tft.setCursor(x, y);
    tft.setTextColor(RED);            
    tft.print(msg);

    //#2 line
    msg = "settings...";
    lineNumber = 2;
    x = getCenterX(msg.length(), charWidthPixelSize);
    y = getCenterY(totalLineToDisplay, lineNumber, charHeightPixelSize);
    tft.setCursor(x, y);
    tft.setTextColor(RED);            
    tft.print(msg);
}

void displayOriginScreen() {

    int totalLineToDisplay = 2;     

    //Text Size 1 - 6x8
    //Text Size 2 - 12x16
    tft.setTextSize(1);         
    int charWidthPixelSize = 6;
    int charHeightPixelSize = 8;

    //#1 line
    String msg = "Retrieving";
    int lineNumber = 1;
    int x = getCenterX(msg.length(), charWidthPixelSize);
    int y = getCenterY(totalLineToDisplay, lineNumber, charHeightPixelSize);
    tft.setCursor(x, y);
    tft.setTextColor(RED);            
    tft.print(msg);

    //#2 line
    msg = "bed origin...";
    lineNumber = 2;
    x = getCenterX(msg.length(), charWidthPixelSize);
    y = getCenterY(totalLineToDisplay, lineNumber, charHeightPixelSize);
    tft.setCursor(x, y);
    tft.setTextColor(RED);            
    tft.print(msg);
}

void displayMainMenuScreen() {

    //Text Size 1 - 6x8
    //Text Size 2 - 12x16
    tft.setTextSize(2);  
    tft.setCursor(0,0);
    tft.setTextColor(BLUE);     
    tft.print(F("MAIN MENU"));

    tft.setTextSize(1);  
    tft.setCursor(0,21); //16 + 5

    if (currentOptionSelected == SETTINGS_OPTION) {
        tft.setTextColor(BLACK, WHITE);    
    }    
    else {
        tft.setTextColor(WHITE, BLACK);    
    }

    tft.print(F("Settings     ->"));

    //tft.setTextSize(1);  
    tft.setCursor(0,32); //21 + 8 + 3
    
    if (currentOptionSelected == CONTROL_OPTION) {
        tft.setTextColor(BLACK, WHITE);    
    }    
    else {
        tft.setTextColor(WHITE, BLACK);    
    }

    tft.print(F("Control      ->"));

    //Current settings
    //tft.setTextSize(1);  
    tft.setCursor(0,53); 
    tft.setTextColor(BLUE);            
    tft.print(F("Current settings : "));    

    //tft.setTextSize(1);  
    tft.setCursor(0,64); 
    tft.setTextColor(GREEN);            
    tft.print(F("Mat. thickness: "));
    tft.setTextColor(RED);    
    tft.print(String(bedSettings.materialThickness_mm));
    tft.setTextColor(GREEN);    
    tft.print(F(" mm"));

    //tft.setTextSize(1);  
    tft.setCursor(0,77);  //64 + 8 + 3
    tft.setTextColor(GREEN);            
    tft.print(F("Bed ori from focal pt: "));
    tft.setTextColor(RED);    
    tft.print(String(bedSettings.bedOffsetFromOriginToFocalPoint_mm));
    tft.setTextColor(GREEN);    
    tft.print(F(" mm"));

    //tft.setTextSize(1);  
    tft.setCursor(0,96);  //77 + 8 + 8 + 3
    tft.setTextColor(GREEN);            
    tft.print(F("Bed level: "));
    tft.setTextColor(RED);    

    switch (bedComputedSettings.bed_level_status)
    {        
        case FROM_ORIGIN_TO_BED_FOCAL_POINT_LEVEL:
        tft.print(F("bed focal"));
        break;

        case FROM_ORIGIN_TO_MATERIAL_ENGRAVE_FOCAL_POINT_LEVEL:
        tft.print(F("mat. focal (engrave)"));
        break;

        case FROM_ORIGIN_TO_MATERIAL_CUT_FOCAL_POINT_LEVEL:
        tft.print(F("mat. focal (cut)"));
        break;

        case FROM_ORIGIN_LEVEL:
        tft.print(F("origin"));
        break;       
    }

    tft.setCursor(0,115);  //96 + 8 + 8 + 3
    tft.setTextColor(GREEN);            
    tft.print(F("Bed level: "));
    tft.setTextColor(RED);

    //bed.currentPosition() = in STEPS
    float currentBedPos_mm = bed.currentPosition() / STEPS_PER_MM;
    //debug_message("Curr pos : " + String(bed.currentPosition()), false);

    tft.print(String(currentBedPos_mm, 2));
    tft.setTextColor(GREEN);    
    tft.print(F(" mm"));
}

void displayControlScreen() {

    //Text Size 1 - 6x8
    //Text Size 2 - 12x16
    tft.setTextSize(1);  
    tft.setCursor(0,0);
    tft.setTextColor(BLUE);     
    tft.print(F("CONTROL MENU"));

    //tft.setTextSize(1);  
    tft.setCursor(0,13); //8 + 5

    if (currentOptionSelected == MOVE_FROM_ORIGIN_TO_BED_FOCAL_OPTION) {
        tft.setTextColor(BLACK, WHITE);    
    }    
    else {
        tft.setTextColor(WHITE, BLACK);    
    }

    tft.print(F("Move from origin to bed focal")); 

    //tft.setTextSize(1);  
    tft.setCursor(0,34); //13 + 8 + 8 + 5

    if (currentOptionSelected == MOVE_FROM_ORIGIN_TO_MATERIAL_FOCAL_ENGRAVE_OPTION) {
        tft.setTextColor(BLACK, WHITE);    
    }    
    else {
        tft.setTextColor(WHITE, BLACK);    
    }    
    tft.print(F("Move from origin to material focal (engrave)")) ; 

    //tft.setTextSize(1);  
    tft.setCursor(0,63); //34 + 8 + 8 + 8 + 5

    if (currentOptionSelected == MOVE_FROM_ORIGIN_TO_MATERIAL_FOCAL_CUT_OPTION) {
        tft.setTextColor(BLACK, WHITE);    
    }    
    else {
        tft.setTextColor(WHITE, BLACK);    
    }
    
    tft.print(F("Move from origin to material focal (cut)")) ; 

    //tft.setTextSize(1);  
    tft.setCursor(0,84); //63 + 8 + 8 +5 

    if (currentOptionSelected == MOVE_TO_BED_ORIGIN) {
        tft.setTextColor(BLACK, WHITE);    
    }    
    else {
        tft.setTextColor(WHITE, BLACK);    
    }
    
    tft.print(F("Move to bed origin")) ;

    //tft.setTextSize(1);  
    tft.setCursor(0,105); //84 + 8 + 8 + 5 

    if (currentOptionSelected == BACK_OPTION) {
        tft.setTextColor(BLACK, WHITE);    
    }    
    else {
        tft.setTextColor(WHITE, BLACK);    
    }
    
    tft.print(F("Back <-")) ;

}

void displaySettingsScreen() {

    //Text Size 1 - 6x8
    //Text Size 2 - 12x16
    tft.setTextSize(1);  
    tft.setCursor(0,0);
    tft.setTextColor(BLUE);     
    tft.print(F("SETTINGS MENU"));

    tft.setTextSize(1);  
    tft.setCursor(0,13); //8 + 5

    if (currentOptionSelected == BED_OFFSET_FROM_ORIGIN_TO_FOCAL_OPTION) {
        tft.setTextColor(BLACK, WHITE);    
    }    
    else {
        tft.setTextColor(WHITE, BLACK);    
    }

    tft.print("Bed offset from origin to focal ("+String(bedSettings.bedOffsetFromOriginToFocalPoint_mm)+" mm) ->"); 

    tft.setTextSize(1);  
    tft.setCursor(0,34); //13 + 8 + 8 + 5

    if (currentOptionSelected == THICKNESS_SETTINGS_OPTION) {
        tft.setTextColor(BLACK, WHITE);    
    }    
    else {
        tft.setTextColor(WHITE, BLACK);    
    }    
    tft.print("Material thickness ("+String(bedSettings.materialThickness_mm)+" mm) ->") ; 

    tft.setTextSize(1);  
    tft.setCursor(0,55); //34 + 8 + 8 + 5

    if (currentOptionSelected == SAVE_SETTINGS_OPTION) {
        tft.setTextColor(BLACK, WHITE);    
    }    
    else {
        tft.setTextColor(WHITE, BLACK);    
    }
    
    tft.print(F("Save settings")) ; 

    tft.setTextSize(1);  
    tft.setCursor(0,68); //55 + 8 +5 

    if (currentOptionSelected == BACK_OPTION) {
        tft.setTextColor(BLACK, WHITE);    
    }    
    else {
        tft.setTextColor(WHITE, BLACK);    
    }
    
    tft.print(F("Back <-")) ; 
}

void displayBedOffsetFromOriginToFocalScreen() {

    tft.setTextSize(1);  
    tft.setCursor(0,13); //8 + 5

    tft.setTextColor(WHITE, BLACK);    

    tft.print("Bed offset from origin to focal : " + String(bedSettings.bedOffsetFromOriginToFocalPoint_mm) + "   "); //Space required otherwise 10 will become 90 when decreasing for instance 
}

void displayMaterialThicknessScreen() {

    tft.setTextSize(1);  
    tft.setCursor(0,13); //8 + 5

    tft.setTextColor(WHITE, BLACK);    

    tft.print("Materiel thickness : " + String(bedSettings.materialThickness_mm) + "   "); //Space required otherwise 10 will become 90 when decreasing for instance 
}
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
void loop() {
        
    encoderButton.loop(); // MUST call the loop() function first to properly manage button.

    handleEncoderButtonManagement();

    handleSelectionOptionManagement();

    handleMotorManagement();  
}

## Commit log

2021-02-28 Huge refactoring commit + making the documentation up to date
    [motorized-bed-base-corner-frame.stl, motorized-bed-bottom-left-corner.stl, motorized-bed-bottom-right-corner.stl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]
2021-02-28 Update motorized bed doc
2021-03-06 add birdhouse sample and doc about how to set proper laser focus
2021-03-13 add some pics and how to use bed level software
2021-03-13 add stl missing parts (Thanks goes to @tgv26)
    [motorized-bed-nema17-holder.stl, motorized-bed-upper-right-corner.stl]
2021-03-13 Change stl file name
    [motorized-bed-base-upper-right-corner.stl]
2021-03-13 add missing stl file
    [motorized-bed-upper-right-corner.stl]
2021-12-29 add flowmeter holder
    [flowmeter_holder.FCStd, flowmeter_holder.stl]
2021-12-29 update design
    [flowmeter_holder.FCStd, flowmeter_holder.stl]
